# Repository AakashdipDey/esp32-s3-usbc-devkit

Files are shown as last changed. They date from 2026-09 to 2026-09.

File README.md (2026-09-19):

# ESP32-S3 High-Performance Development Board with Dual USB-C







A high-reliability, custom-engineered **4-layer development platform** built around the **Espressif ESP32-S3-MINI-1-N8** microcontroller (Xtensa® 32-bit LX7 dual-core up to 240 MHz, 8MB Quad SPI Flash, Wi-Fi 4 & Bluetooth 5.0 LE). 

Designed for professional embedded systems development, this board integrates **dual USB Type-C connectivity**—providing both native hardware USB-OTG/JTAG debugging and an isolated high-speed UART interface via an onboard **FTDI FT231XQ-R** bridge with transistor-automated hardware flashing.

---

## Key Hardware Architectural Features

### 1. Dual USB Type-C Architecture
* **Native USB-OTG Port (`J3`):** Connected directly to the ESP32-S3 native USB D+/D- pins for hardware USB-JTAG debugging, direct CDC serial, DFU bootloading, and high-speed USB device/host operation.
* **FTDI UART Bridge Port (`J4`):** Dedicated programming and serial console port driven by the **FTDI FT231XQ-R** (Full-Speed USB to Full UART in QFN-20). Eliminates driver complications and provides dedicated, uninterrupted hardware logging during firmware execution.
* **USB-C Compliance:** Dual 5.1kΩ configuration channel (CC1/CC2) pull-down termination on each receptacle to ensure full compliance with USB Type-C Current Mode sourcing up to 3A @ 5V.

### 2. Transistor-Automated Boot & Reset Circuitry
* Utilizes a dual NPN transistor network (**Comchip SS8050-G**) cross-coupling FTDI `DTR` and `RTS` signals into the ESP32-S3 `CHIP_PU` (Reset) and `GPIO0` (Boot) lines.
* Enables hands-free firmware flashing from ESP-IDF, PlatformIO, or Arduino IDE without needing manual button presses.
* Integrated tactile switches (**C&K PTS645SH50SMTR92LFS**) provide manual hardware override for Reset and Boot mode selection.

### 3. Industrial Power Distribution & Thermal Stability
* **High-Current LDO Regulator:** **Texas Instruments TL1963A-33DCYR** (SOT-223-4).
  * Rated for continuous **1.5A output** at 3.3V with ultra-fast transient response to effortlessly absorb the steep 400mA+ current spikes characteristic of 2.4GHz 802.11b/g/n RF transmissions.
  * Ultra-low output noise voltage (40 µVRMS over 10 Hz to 100 kHz) for analog/ADC integrity.
* **Decoupling Network:** Distributed 0402 ceramic multi-layer capacitors (Samsung X7R/X5R 100nF, 4.7µF, and 10µF bulk decoupling) situated immediately adjacent to module power pins and LDO terminals.

### 4. Robust Transient & ESD Protection
* **Littelfuse AQ3045-01ETG** bidirectional TVS diode arrays placed at the boundary of all external USB data and VBUS lines (SOD-882 footprint).
* Rated for **±30kV contact and air ESD discharges** (IEC 61000-4-2) and up to 12A (8/20µs) lightning surge protection, ensuring operational resilience on testbenches and field deployments.

---

## PCB Stackup & Manufacturing Specifications

The board utilizes a symmetrical **4-layer stackup** designed for optimal EMI suppression and consistent ground reference planes:

| Layer # | Layer Name | Layer Type | Copper Weight | Function / Net Allocation |
|:---:|:---|:---|:---:|:---|
| **L1**  | Top Layer  | Signal / Component | 1.0 oz (35 µm) | Critical high-speed signals, RF keepouts, USB differential traces |
| **L2**  | Inner Layer 1 | Internal Plane | 1.0 oz (35 µm) | Continuous, unbroken **Ground Reference Plane (GND)** |
| **L3**  | Inner Layer 2 | Internal Plane | 1.0 oz (35 µm) | Split Power Plane (**3.3V System Rail & 5V VBUS Distribution**) |
| **L4**  | Bottom Layer | Signal / Ground | 1.0 oz (35 µm) | Low-speed routing, non-critical breakouts, ground shield polygon pour |

### Physical Parameters
* **Board Dimensions:** Standard breadboard-friendly form factor with 2.54mm (0.1") dual-row headers.
* **Minimum Trace Width:** 6 mil (0.152 mm)
* **Minimum Clearance:** 6 mil (fine-pitch IC rooms), 8 mil (general signals), 10 mil (power polygons)
* **Differential Impedance:** 90Ω ±10% controlled differential impedance for USB D+/D- signal lines (`DIFF90` class).
* **DRC Verification:** **0 Violations** (verified against standard IPC-2221 Class 2 rules).

---

## Hardware Visualizations

### Board Layout (Top & Bottom)
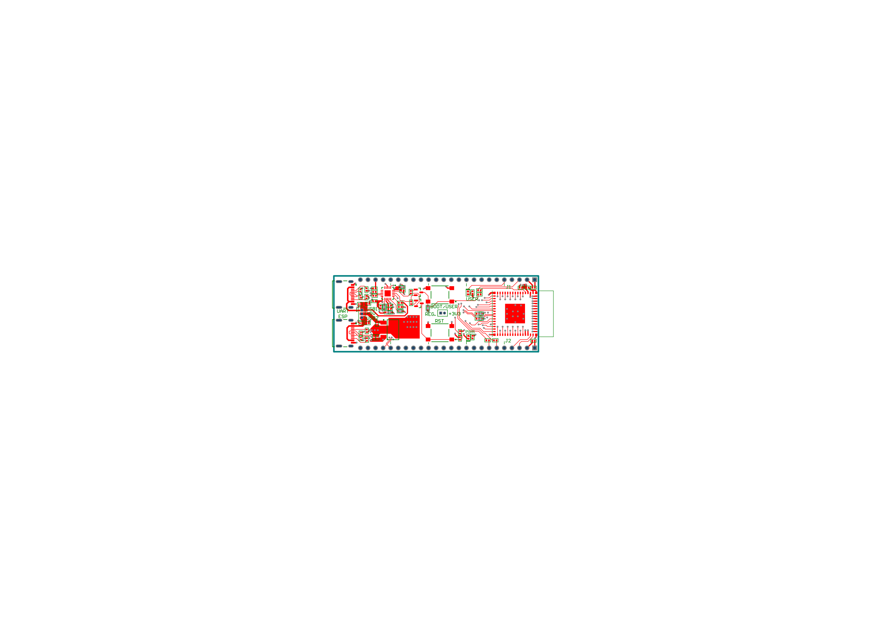
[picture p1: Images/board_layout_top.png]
Board Layout Top

*Figure 1: High-density component placement and routing visualization (Top Layer).*

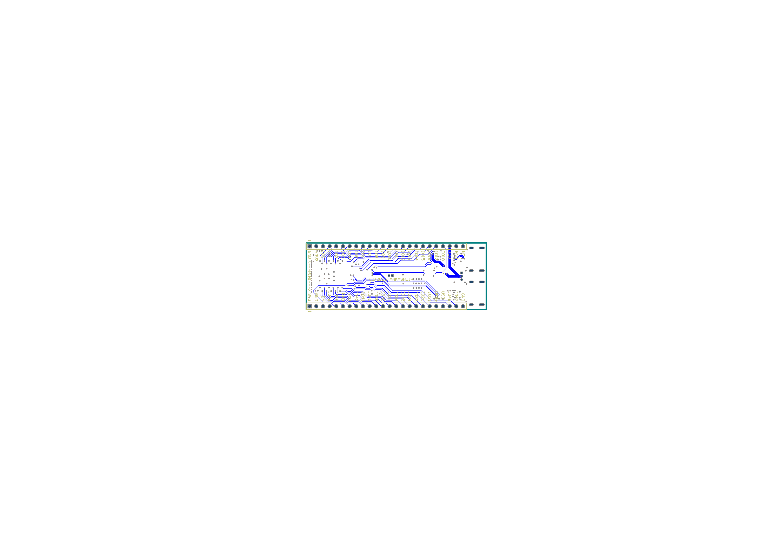
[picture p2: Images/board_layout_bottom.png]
Board Layout Bottom

*Figure 2: Power and ground distribution visualization (Bottom Layer).*

---

## Bill of Materials (BOM Summary)

Full engineering BOM is available in both [`Documentation/Bill_of_Materials.xlsx`](Documentation/Bill_of_Materials.xlsx) and [`Documentation/Bill_of_Materials.csv`](Documentation/Bill_of_Materials.csv).

| Designator | Quantity | Description | Manufacturer | MPN | Package |
|:---|:---:|:---|:---|:---|:---|
| **U1** | 1 | 2.4GHz Wi-Fi/BLE Dual-Core SoC Module, 8MB SPI Flash | Espressif Systems | `ESP32-S3-MINI-1-N8` | SMD Module |
| **U2** | 1 | Full-Speed USB to Full UART Bridge Controller | FTDI | `FT231XQ-R` | QFN-20 |
| **U3** | 1 | Low-Noise 1.5A Fast-Transient LDO Linear Regulator, 3.3V | Texas Instruments | `TL1963A-33DCYR` | SOT-223-4 |
| **J3, J4** | 2 | USB 2.0 Type-C Receptacle, 24-Pin Right-Angle SMD | Molex | `217179-0001` | SMT Hybrid |
| **J1, J2** | 2 | 24-Pin Breakout Header, 2.54mm Pitch | Molex | `0022284245` | Through-Hole |
| **Q1, Q2** | 2 | NPN Bipolar Transistor 25V 1.5A (Auto-Reset Circuit) | Comchip | `SS8050-G` | SOT-23-3 |
| **D3-D8** | 6 | Bidirectional TVS Diode 5.3V Clamping 12A (ESD Protection) | Littelfuse | `AQ3045-01ETG` | SOD-882 |
| **D1** | 1 | Yellow-Green LED (3.3V Power Good Indicator) | Vishay | `VLMG1500-GS08` | 0402 SMD |
| **D2** | 1 | Red LED (UART Activity / Status Indicator) | Vishay | `VLMS1500-GS08` | 0402 SMD |
| **SW1, SW2** | 2 | SPST Tactile Pushbutton (Reset & Boot Mode) | C&K Components | `PTS645SH50SMTR92LFS` | SMD Tact |
| **C1-C16** | 15 | Ceramic Capacitors (100nF, 1µF, 4.7µF, 10µF) 10V-50V X7R/X5R | Samsung Electro-Mechanics | Multiple | 0402 SMD |
| **R1-R24** | 22 | Precision SMD Thick Film Resistors (0R, 27R, 1K, 4.7K, 5.1K, 10K) | Yageo | Multiple | 0402 SMD |

---

## Pinout Mapping

The board breaks out all functional GPIOs of the ESP32-S3-MINI module onto two 24-pin 0.1" (2.54mm) headers (`J1` and `J2`), fully documented in [`Documentation/ESP32_Pinout_Sheet.xlsx`](Documentation/ESP32_Pinout_Sheet.xlsx):

* **Power & Ground:** 3.3V regulated rail, 5V VBUS input, multiple low-impedance ground returns.
* **Analog Inputs:** ADC1 channels 0-9 and ADC2 channels 0-9.
* **High-Speed Busses:** SPI / Dual / Quad SPI lines, hardware UART, I2C, and PWM timers.
* **JTAG & Debug:** Dedicated USB-JTAG pins routed to native USB-C connector.

---

## Repository Structure

```
├── Hardware/
│   ├── ESP32 with USBC.PrjPcb         # Altium Project master file
│   ├── ESP32 with USBC.SchDoc         # Complete schematic sheets
│   ├── ESP32 with USBC.PcbDoc         # 4-layer routed PCB layout
│   ├── PcbLib.PcbLib                  # Custom component PCB footprints
│   ├── Schlib.SchLib                  # Custom schematic symbols
│   └── Job.OutJob                     # Altium Output Job configuration
├── Fabrication/
│   ├── ESP32 with USBC.GTL            # Top Copper Gerber
│   ├── ESP32 with USBC.G1             # Inner Ground Plane 1
│   ├── ESP32 with USBC.GP1            # Inner Power Plane 2
│   ├── ESP32 with USBC.GBL            # Bottom Copper Gerber
│   ├── ESP32 with USBC.GTO / .GBO     # Top & Bottom Silkscreen
│   ├── ESP32 with USBC.GTS / .GBS     # Top & Bottom Soldermask
│   ├── ESP32 with USBC.DRR / .TXT     # NC Drill definition & coordinates
│   ├── Pick_and_Place.csv             # Automated SMT Pick & Place centroids
│   └── Design_Rule_Check.drc          # Altium DRC report (0 errors)
├── Documentation/
│   ├── Bill_of_Materials.xlsx         # Engineering BOM with distributor part numbers
│   ├── Bill_of_Materials.csv          # Machine-readable BOM
│   ├── ESP32_Pinout_Sheet.xlsx        # Pinout and alternate function matrix
│   ├── ESP32-S3-MINI-1_Datasheet.pdf  # Espressif hardware datasheet
│   └── Board_Checking.pdf             # Manufacturing layout documentation
├── Images/
│   ├── board_layout_top.png           # Top layer rendering
│   └── board_layout_bottom.png        # Bottom layer rendering
└── README.md
```

---

## Author & Contact

**Aakashdip Dey**  
*Hardware & Embedded Electronics Engineer*  
* Vellore, India  
* GitHub: [@AakashdipDey](https://github.com/AakashdipDey)

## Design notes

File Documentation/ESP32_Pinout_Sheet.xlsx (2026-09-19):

1 | GND_01
2 | GND_02
3 | 3V3
4 | GPIO0/RTC_GPIO0
5 | GPIO1/RTC_GPIO1/TOUCH1/ADC1_CH0
6 | GPIO2/RTC_GPIO2/TOUCH2/ADC1_CH1
7 | GPIO3/RTC_GPIO3/TOUCH3/ADC1_CH2
8 | GPIO4/RTC_GPIO4/TOUCH4/ADC1_CH3
9 | GPIO5/RTC_GPIO5/TOUCH5/ADC1_CH4
10 | GPIO6/RTC_GPIO6/TOUCH6/ADC1_CH5
11 | GPIO7/RTC_GPIO7/TOUCH7/ADC1_CH6
12 | GPIO8/RTC_GPIO8/TOUCH8/ADC1_CH7/SUBSPICS1
13 | GPIO9/RTC_GPIO9/TOUCH9/ADC1_CH8/FSPIHD/SUBSPIHD
14 | GPIO10/RTC_GPIO10/TOUCH10/ADC1_CH9/FSPICS0/FSPIIO4/SUBSPICS0
15 | GPIO11/RTC_GPIO11/TOUCH11/ADC2_CH0/FSPID/FSPIIO5/SUBSPID
16 | GPIO12/RTC_GPIO12/TOUCH12/ADC2_CH1/FSPICLK/FSPIIO6/SUBSPICLK
17 | GPIO13/RTC_GPIO13/TOUCH13/ADC2_CH2/FSPIQ/FSPIIO7/SUBSPIQ
18 | GPIO14/RTC_GPIO14/TOUCH14/ADC2_CH3/FSPIWP/FSPIDQS/SUBSPIWP
19 | GPIO15/RTC_GPIO15/U0RTS/ADC2_CH4/XTAL_32K_P
20 | GPIO16/RTC_GPIO16/U0CTS/ADC2_CH5/XTAL_32K_N
21 | GPIO17/RTC_GPIO17/U1TXD/ADC2_CH6
22 | GPIO18/RTC_GPIO18/U1RXD/ADC2_CH7/CLK_OUT3
23 | USB_D-/RTC_GPIO19/GPIO19/U1RTS/ADC2_CH8/CLK_OUT2
24 | USB_D+/RTC_GPIO20/GPIO20/U1CTS/ADC2_CH9/CLK_OUT1
25 | GPIO21/RTC_GPIO21
26 | GPIO26/SPICS1
27 | GPIO47/SPICLK_P_DIFF/SUBSPICLK_P_DIFF
28 | GPIO33/SPIIO4/FSPIHD/SUBSPIHD
29 | GPIO34/SPIIO5/FSPICS0/SUBSPICS0
30 | GPIO48/SPICLK_N_DIFF/SUBSPICLK_N_DIFF
31 | GPIO35/SPIIO6/FSPID/SUBSPID
32 | GPIO36/SPIIO7/FSPICLK/SUBSPICLK
33 | GPIO37/SPIDQS/FSPIQ/SUBSPIQ
34 | GPIO38/FSPIWP/SUBSPIWP
35 | MTCK/GPIO39/CLK_OUT3/SUBSPICS1
36 | MTDO/GPIO40/CLK_OUT2
37 | MTDI/GPIO41/CLK_OUT1
38 | MTMS/GPIO42
39 | U0TXD/GPIO43/CLK_OUT1
40 | U0RXD/GPIO44/CLK_OUT2
41 | GPIO45
42 | GND
43 | GND
44 | GPIO46
45 | EN
46 | GND_46
47 | GND_47
48 | GND_48
49 | GND_49
50 | GND_50
51 | GND_51
52 | GND_52
53 | GND_53
54 | GND_54
55 | GND_55
56 | GND_56
57 | GND_57
58 | GND_58
59 | GND_59
60 | GND_60
61 | GND_61
62 | GND_62
63 | GND_63
64 | GND_64
65 | GND_65
66 | GND_66
67 | GND_67
68 | GND_68
69 | GND_69
70 | GND_70
71 | GND_71
72 | GND_72
73 | GND_73

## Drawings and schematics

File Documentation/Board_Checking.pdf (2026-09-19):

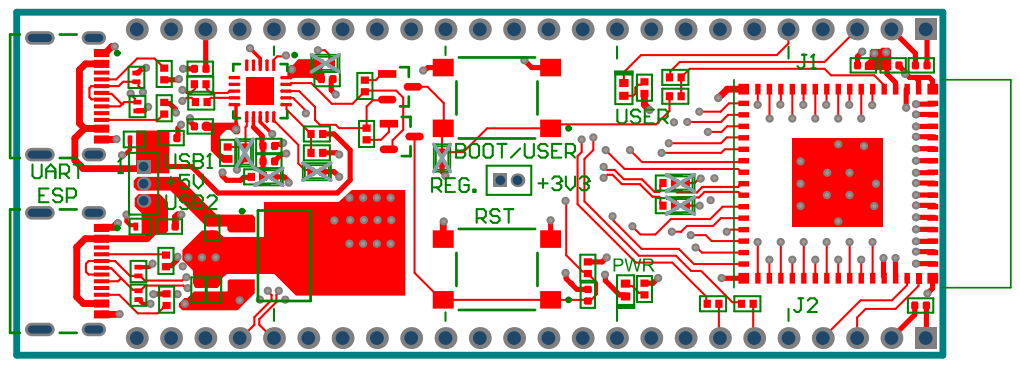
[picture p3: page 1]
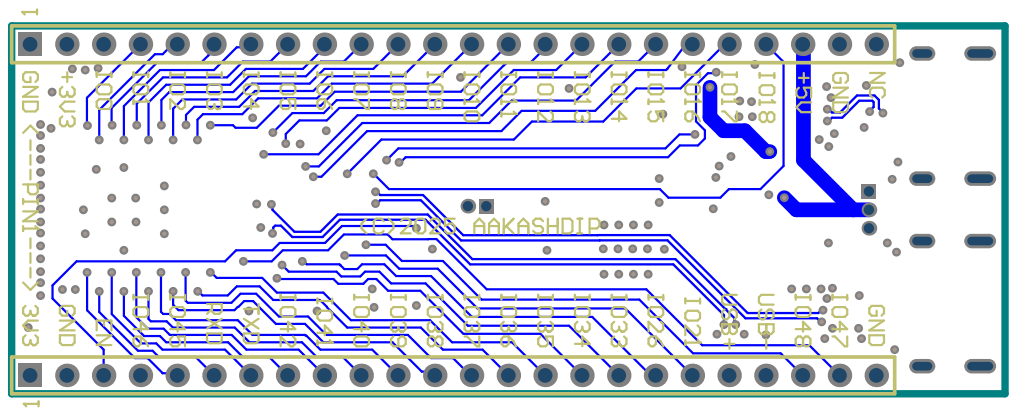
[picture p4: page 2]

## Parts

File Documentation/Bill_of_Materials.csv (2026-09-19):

Comment | Description | Designator | Footprint | LibRef | Quantity | LCSC Part Number | Manufacturer Part Number | Manufacturer | Supplier Part Number | Supplier
100nF, 50V | CAP CER 0.1UF 50V X7R 0402 | C1, C3, C4, C5, C6, C8, C9, C10, C15 | CAPC1005X55N | CL05B104KB54PNC | 9 | C307331 | CL05B104KB54PNC | Samsung | 1276-CL05B104KB54PNCCT-ND | Digikey
4u7, 16V | CAP CER 4.7UF 16V X5R 0402 | C2, C11 | CAPC1005X55N | CL05A475MO5NUNC | 2 | C318563 | CL05A475MO5NUNC | Samsung | 1276-6836-1-ND | Digikey
10uF, 10V | CAP CER 10UF 10V X5R 0402 | C12, C13, C14 | CAPC1005X55N | CL05A106MP8NUB8 | 3 | C307415 | CL05A106MP8NUB8 | Samsung | 1276-6830-1-ND | Digikey
1uF, 35V | CAP CER 1UF 35V X5R 0402 | C16 | CAPC1005X55N | CL05A105KL5NRNC | 1 | C307413 | CL05A105KL5NRNC | Samsung | 1276-6796-1-ND | Digikey
GREEN | LED YLW-GRN 0402 SMD | D1 | LED0402G | VLMG1500-GS08 | 1 | C511404 | VLMG1500-GS08 | Vishay | VLMG1500-GS08CT-ND | Digikey
RED | LED RED 0402 SMD | D2 | LED0402R | VLMS1500-GS08 | 1 | C511370 | VLMS1500-GS08 | Vishay | VLMS1500-GS08CT-ND | Digikey
AQ3045-01ETG | TVS DIODE 5.3VWM 12VC SOD882 | D3, D4, D5, D6, D7, D8 | SOD882 | AQ3045-01ETG | 6 | C3710326 | AQ3045-01ETG | Littelfuse | F9321CT-ND | Digikey
0022284245 | CONN HEADER VERT 24POS 2.54MM | J1, J2 | HDR_1X24_2.54MM | 0022284245 | 2 | C7145888 | 0022284245 | Molex | 900-0022284245-ND | Digikey
217179-0001 | CONN RCP USB2.0 TYP C 24P SMD RA | J3, J4 | FP-2171790001-MFG | 217179-0001 | 2 | C3197684 | 217179-0001 | Molex | 900-2171790001CT-ND | Digikey
FTS-103-01-F-S | CONN HEADER VERT 3POS 1.27MM | J5 | HDR_1X3_1.27MM | FTS-103-01-F-S | 1 | C3333578 | FTS-103-01-F-S | Samtec | 612-FTS-103-01-F-S-ND | Digikey
FTS-102-01-F-S | CONN HEADER VERT 2POS 1.27MM | J6 | HDR_1X2_1.27MM | FTS-102-01-F-S | 1 | C6045317 | FTS-102-01-F-S | Samtec | SAM15176-ND | Digikey
M50-1920005 | CONN SHUNT 1.27MM RED | LINK1, LINK2 |  | M50-1920005 | 2 | C6985646 | M50-1920005 | Harwin | 952-1727-ND | Digikey
SS8050-G | TRANS NPN 25V 1.5A SOT23-3 | Q1, Q2 | FP-SS8050-G-IPC_B | SS8050-G | 2 | C164886 | SS8050-G | Comchip | 641-1790-1-ND | Digikey
0R | RES 0 OHM JUMPER 1/16W 0402 | R1, R8, R19, R20, R23, R24 | RESC1005X37N | RC0402JR-070RL | 6 | C60485 | RC0402JR-070RL | Yageo | 311-0.0JRCT-ND | Digikey
1K | RES 1K OHM 1% 1/16W 0402 | R3, R4 | RESC1005X37N | RC0402FR-071KL | 2 | C106235 | RC0402FR-071KL | Yageo | 311-1.00KLRCT-ND | Digikey
27R | RES 27 OHM 1% 1/16W 0402 | R6, R7, R21, R22 | RESC1005X37N | RC0402FR-0727RL | 4 | C138021 | RC0402FR-0727RL | Yageo | YAG3086CT-ND | Digikey
4K7 | RES 4.7K OHM 1% 1/16W 0402 | R10 | RESC1005X37N | RC0402FR-074K7L | 1 | C105871 | RC0402FR-074K7L | Yageo | 311-4.7KLRCT-ND | Digikey
5K1 | RES SMD 5.1K OHM 1% 1/16W 0402 | R11, R12, R14, R15 | RESC1005X37N | AC0402FR-075K1L | 4 | C144745 | AC0402FR-075K1L | Yageo | YAG3503CT-ND | Digikey
10K | RES SMD 10K OHM 1% 1/16W 0402 | R13, R16, R17, R18 | RESC1005X37N | AC0402FR-0710KL | 4 | C144807 | AC0402FR-0710KL | Yageo | YAG3436CT-ND | Digikey
PTS645SH50SMTR92LFS | SWITCH TACTILE SPST-NO 0.05A 12V | SW1, SW2 | FP-PTS645SH50SMTR92LFS-MFG | PTS645SH50SMTR92LFS | 2 | C221869 | PTS645SH50SMTR92LFS | ITT C&K | CKN9085CT-ND | Digikey
ESP32-S3-MINI-1-N8 | SMD Module, ESP32-S3FN8, 8 mb Sp | U1 | XCVR_ESP32-S3-MINI-1-N8 | ESP32-S3-MINI-1-N8 | 1 | C2913206 | ESP32-S3-MINI-1-N8 | Espressif Systems | 1965-ESP32-S3-MINI-1-N8CT-ND | Digikey
FT231XQ-R | IC USB SERIAL FULL UART 20QFN | U2 | FP-QFN-20-IPC_B | FT231XQ-R | 1 | C132159 | FT231XQ-R | FTDI | 768-1128-1-ND | Digikey
TL1963A-33DCYR | IC REG LINEAR 3.3V 1.5A SOT223-4 | U3 | DCY0004A_N | TL1963A-33DCYR | 1 | C181262 | TL1963A-33DCYR | Texas Instruments | 296-24897-1-ND | Digikey

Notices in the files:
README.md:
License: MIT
